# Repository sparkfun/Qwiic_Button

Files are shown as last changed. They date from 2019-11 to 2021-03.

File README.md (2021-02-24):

SparkFun Qwiic Button
========================================
<table class="table table-hover table-striped table-bordered">
  <tr align="center">
   <td></td>
   <td></td>
   <td></td>
  </tr>
  <tr align="center">
    <td><a href="https://www.sparkfun.com/products/15932">SparkFun Qwiic Button - Red <br />(BOB-15932)</a></td>
    <td><a href="https://www.sparkfun.com/products/16842">SparkFun Qwiic Button - Green <br />(BOB-16842)</a></td>
    <td><a href="https://www.sparkfun.com/products/15931">SparkFun Qwiic Button Breakout <br />(BOB-15931)</a></td>
  </tr>
</table>

The SparkFun Qwiic Button is an I<sup>2</sup>C enabled button with a built-in LED, interrupts, variable I<sup>2</sup>C address, and onboard button queues.

Repository Contents
-------------------

* **/Documentation** - Data sheets, additional product information
* **/Hardware** - Eagle design files (.brd, .sch)
* **/Firmware** - The latest firmware on the Qwiic Button boards
* **/Hardware/Production** - Production panel files (.brd)

Documentation
--------------
* **[SparkFun Qwiic Button Hookup Guide](https://learn.sparkfun.com/tutorials/sparkfun-qwiic-button-hookup-guide/all)** - Basic Hookup Guide.
* **[SparkFun Qwiic Button Arduino Library](https://github.com/sparkfun/SparkFun_Qwiic_Button_Arduino_Library)** - Arduino library for the Qwiic Button and Switch.
* **[SparkFun Qwiic Button Python Package](https://github.com/sparkfun/Qwiic_Button_Py)** - Python package for the Qwiic Button and Qwiic Switch

Product Versions
--------------

* [BOB-15932](https://www.sparkfun.com/products/15932) - SparkFun Red Version with red LED pushbutton
* [BOB-16842](https://www.sparkfun.com/products/16842) - SparkFun Red Version with green LED pushbutton
* [BOB-15931](https://www.sparkfun.com/products/15931) - SparkFun Red Version without button
* [SPX-15584](https://www.sparkfun.com/products/15584) - Original SparkX version of the Qwiic Button.

License Information
-------------------

This product is _**open source**_! 

Please review the LICENSE.md file for license information. 

If you have any questions or concerns on licensing, please contact technical support on our [SparkFun forums](https://forum.sparkfun.com/viewforum.php?f=152).

Distributed as-is; no warranty is given.

- Your friends at SparkFun.

_<COLLABORATION CREDIT>_

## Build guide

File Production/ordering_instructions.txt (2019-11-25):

panel size, 91x91mm
PCB thickness, 1.6mm
number of layers, 2
soldermask color, Black
silkscreen color, White
oz copper, 1oz
finish, HASL lead free
stencils, top+bottom
pcs per panel, 9
min trace width, 0.152400mm / 0.006000in
min drill size, 0.304800mm / 0.012000in

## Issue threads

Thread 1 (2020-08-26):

Pop queue not working as expected

alchitry, 2020-08-26:
### Subject of the issue
I'm trying to get the Qwiic button working with the RedBoard Turbo and have setup all the libraries and am able to talk to the button.

Stuff like button.isPressed() works exactly as expected. However, the queue stuff isn't quite working properly.

I thought I'd use the pressed queue to make sure I got an accurate count of how many times the button was pressed. I'm using button.isPressedQueueEmpty() to check if the queue is empty before calling button.popPressedQueue() to remove a press. However, popPressedQueue() doesn't seem to remove an element from the queue as expected.

After clicking the button once, isPressedQueueEmpty() returns false regardless of how many times popPressedQueue() is called. Also isPressedQueueFull() always returns true once I press the button 15 times.

I've checked the firmware of the button and it matches the latest in the GitHub (258, 0x01 major, 0x02 minor)

I've also tried writing 0x01 to pressedQueueStatus register directly and reading it back. It reads 0 so the popRequest bit is either never set or cleared when the request is supposedly processed.

### Your workbench
* What development board or microcontroller are you using?
RedBoard Turbo

* What version of hardware or breakout board are you using?
258 (current firmware)

* How is the breakout board wired to your microcontroller?
Qwiic

* How is everything being powered?
5V regulator to the RedBoard Turbo, button is powered over Qwiic

### Steps to reproduce
Connect button to RedBoard Turbo (or likely any Qwiic board).

Here's the code I used.

```
#include <SparkFun_Qwiic_Button.h>

const int BLUE_LED = 13;
const int RX_LED = PIN_LED_RXL; // RX LED on pin 25, we use the predefined PIN_LED_RXL to make sure
const int TX_LED = PIN_LED_TXL; // TX LED on pin 26, we use the predefined PIN_LED_TXL to make sure

QwiicButton hourUpButton;
QwiicButton hourDownButton;
QwiicButton minuteUpButton;
QwiicButton minuteDownButton;

void setup() {
  pinMode(BLUE_LED, OUTPUT);
  pinMode(RX_LED, OUTPUT);
  pinMode(TX_LED, OUTPUT);
  digitalWrite(RX_LED, LOW); // TX LED on

  SerialUSB.begin(9600);
  Wire.begin(); //Join I2C bus

  if (minuteDownButton.begin(0x67) == false)
    errorLoop();

  digitalWrite(RX_LED, HIGH); // TX LED off

  while (!SerialUSB);
  digitalWrite(BLUE_LED, HIGH); // Blue LED on
  SerialUSB.println("Starting");

}

void loop() {
  if (minuteDownButton.isPressedQueueEmpty() == false) {
    SerialUSB.println("Minute Down");
    minuteDownButton.popPressedQueue();
  }
  delay(100);
}

void errorLoop() {
  while (1) {
    digitalWrite(RX_LED, LOW); // RX LED on
    delay(333);
    digitalWrite(RX_LED, HIGH); // RX LED off
    digitalWrite(TX_LED, LOW); // TX LED on
    delay(333);
    digitalWrite(TX_LED, HIGH); // TX LED off
    digitalWrite(BLUE_LED, HIGH); // Blue LED on
    delay(333);
    digitalWrite(BLUE_LED, LOW); // Blue LED off
  }
}
```

### Expected behavior
Calling button.popPressedQueue() should remove a press from the queue.

The code should print "Minute Down" once per button press.

### Actual behavior
The queue isn't emptied.

The code prints "Minute Down" continuously after a single press.

wickedbeernut, 2021-02-26:
This bug was opened six months ago.  Can you please help me understand why it hasn't been fixed?  I just bought eight QWIIC buttons and switches and they're all unusable due to this bug.

It appears there are at least two issues ...

The way in which the queueStatusBitField is defined,
```
typedef union {
  struct {
    bool popRequest : 1; //This is bit 0. User mutable, user sets to 1 to pop from queue, we pop from queue and set the bit back to zero.
    bool isEmpty : 1; //user immutable, returns 1 or 0 depending on whether or not the queue is empty
    bool isFull : 1; //user immutable, returns 1 or 0 depending on whether or not the queue is full
    bool: 5;
  };
  uint8_t byteWrapped;
} queueStatusBitField;
```
is inconsistent with the way in which it's being initialized as part of the protectionMap (pressedQueueStatus and clickedQueueStatus),

```
memoryMap protectionMap = {
  0x00,       //id
  0x00,       //firmwareMinor
  0x00,       //firmwareMajor
  {1, 1, 1},  //buttonStatus {isPressed, hasBeenClicked, eventAvailable}
  {1, 1},     //interruptConfig {pressedEnable, clickedEnable}
  0xFFFF,     //buttonDebounceTime
  {0, 0, 1},  //pressedQueueStatus {isFull, isEmpty, popRequest}
  0x00000000, //pressedQueueFront
  0x00000000, //pressedQueueBack
  {0, 0, 1},  //clickedQueueStatus {isFull, isEmpty, popRequest}
  0x00000000, //clickedQueueFront
  0x00000000, //clickedQueueBack
  0xFF,       //ledBrightness
  0xFF,       //ledPulseGranularity
  0xFFFF,     //ledPulseCycleTime
  0xFFFF,     //ledPulseOffTime
  0xFF,       //i2cAddress
};
```

consequently, the popRequest bit is read-only rather than read/write.

The other issue is a byte-alignment issue with the memoryMap.  The uint16_t buttonDebounceTime falls on an odd byte boundary and is being padded.  All of the other fields are off by one byte.

```
typedef struct memoryMap {
  //Button Status/Configuration                       Register Address
  uint8_t id;                                             // 0x00 - Byte 0
  uint8_t firmwareMinor;                                  // 0x01 - Byte 1
  uint8_t firmwareMajor;                                  // 0x02 - Byte 2

  statusRegisterBitField buttonStatus;                    // 0x03 - Byte 3

  //Interrupt Configuration
  interruptConfigBitField interruptConfigure;            // 0x04  - Byte 4

  // <<< PADDED HERE - Byte 5

  uint16_t buttonDebounceTime;                            // 0x05  - Bytes 6 and 7

  //ButtonPressed queue manipulation and status functions
  queueStatusBitField pressedQueueStatus;                 // 0x07 - Byte 8
  unsigned long pressedQueueFront;                        // 0x08 - Bytes 9 through 12
  unsigned long pressedQueueBack;                         // 0x0C  - Bytes 13 through 16

  queueStatusBitField clickedQueueStatus;                 // 0x10 -  - Byte 17
  unsigned long clickedQueueFront;                        // 0x11  - Bytes 18 through 21
  unsigned long clickedQueueBack;                         // 0x15  - Bytes 22 through 25

  //LED Configuration
  uint8_t ledBrightness;                                  // 0x19 - Byte 26
  uint8_t ledPulseGranularity;                            // 0x1A - Byte 27
  uint16_t ledPulseCycleTime;                             // 0x1B - Bytes 28 and 29
  uint16_t ledPulseOffTime;                               // 0x1D - Bytes 30 and 31

  //Device Configuration
  uint8_t i2cAddress;                                     // 0x1F - Byte 32
};
```
I may be all wet.  My interpretation may be a function of the microcontroller I'm testing on.

Assuming I can fix the Qwiic_Button firmware, is there a way I can reprogram my QWIIC buttons and switches?  Or are they pretty much paperweights at this point?

englandsaurus, 2021-02-26:
@wickedbeernut  Are you using a SAMD microcontroller?

wickedbeernut, 2021-02-26:
> @wickedbeernut Are you using a SAMD microcontroller?

You got me there!  SparkFun SAMD51 Thing Plus.

I'll withdraw my comment with respect to the byte-alignment of the memoryMap.  However, I stand by my comment with respect to the way in which the queueStatusBitField is defined and initialized as part of the registerMap and protectionMap (pressedQueueStatus and clickedQueueStatus).

I compiled and uploaded the Qwiic_Button firmware to an Uno.  I added the following Serial.print statements to setup(),

```
  Serial.println();
  Serial.println("memoryMap");
  Serial.println("  Register: registerMap protectionMap");
  for (int x = 0; x < sizeof(memoryMap); x++) {
      Serial.print("    0x");
      Serial.print(x, HEX);
      Serial.print(": ");
      Serial.print(*(registerPointer + x), BIN);
      Serial.print(" ");
      Serial.println(*(protectionPointer + x), BIN);
  }

   bool popRequest;
   bool isEmpty;
   bool isFull;

   popRequest = protectionMap.pressedQueueStatus.popRequest;
   isEmpty = protectionMap.pressedQueueStatus.isEmpty;
   isFull = protectionMap.pressedQueueStatus.isFull;

   Serial.println();
   Serial.println("Protection Map");
   Serial.print("  pressedQueueStatus: ");
   Serial.println(*(protectionPointer + 7), BIN);
   Serial.print("    protectionMap.popRequest: ");
   Serial.println(popRequest);
   Serial.print("    protectionMap.isEmpty: ");
   Serial.println(isEmpty);
   Serial.print("    protectionMap.isFull: ");
   Serial.println(isFull);
   Serial.println();
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
Noam3kCH, 2021-03-02:
I'm also waiting for a solution here

makin-stuff, 2021-03-02:
@wickedbeernut @Noam3kCH I'm working on updating the firmware now. Will update and close this issue when I've got this bug fixed.

makin-stuff, 2021-03-08:
The firmware has been updated and will be present on future Qwiic Button batches. Thanks for your help @wickedbeernut. I've reached out to @Funda in tech support to see if he can issue you some new buttons. He should be reaching out shortly. Thanks

Funda, 2021-03-08:
@wickedbeernut Go ahead and fill out a return ticket here: https://www.sparkfun.com/returns - We will get you taken care of after the ticket has been submitted.

Cheers for now.

wickedbeernut, 2021-03-09:
> @wickedbeernut Go ahead and fill out a return ticket here: https://www.sparkfun.com/returns - We will get you taken care of after the ticket has been submitted.
>
> Cheers for now.

@Funda RMA submitted.  Thank you!

wickedbeernut, 2021-03-13:
> The firmware has been updated and will be present on future Qwiic Button batches. Thanks for your help @wickedbeernut. I've reached out to @Funda in tech support to see if he can issue you some new buttons. He should be reaching out shortly. Thanks

I'd ordered,

(5) Qwiic Switch (SPX-15586)
(2) SparkFun Qwiic Button Breakout (BOB-15931)
(1) Qwiic Arcade - Red (SPX-15591)

Support (@Funda?) is offering to refund my money for the two SparkFun Qwiic button breakout boards (BOB-15931).  Apparently, I'm stuck with the five Qwiic switches (SPX-15586) and arcade button (SPX-15591) because they're "SparkX" (whatever that means).  They all have the same embedded firmware bug.

I don't need a refund.  I need buttons and switches with the new firmware (v01.03).  I don't care if I have to pay for them yet again.  How do I go about ordering Qwiic buttons and switches with the new firmware?

Please help @makin-stuff!

wickedbeernut, 2021-03-18:
> The firmware has been updated and will be present on future Qwiic Button batches. Thanks for your help @wickedbeernut. I've reached out to @Funda in tech support to see if he can issue you some new buttons. He should be reaching out shortly. Thanks

@makin-stuff,

@Funda is refusing to issue me buttons with firmware version 1.3.  I recently purchased,

	(2) SparkFun Qwiic Button Breakout (BOB-15931)
	(5) Qwiic Switch (SPX-15586)
	(1) Qwiic Arcade - Red (SPX-15591)

Can you mail me buttons (BOB-15931) and/or switches (SPX-15586) with firmware version 1.3?  I can send you a Paypal payment?  $10 a piece plus shipping?

makin-stuff, 2021-03-18:
Hi there @wickedbeernut.
Thanks for all the work you did squashing the bug in the qwiic button firmware.
@Funda can send you 8 of [these Qwiic Buttons](https://www.sparkfun.com/products/15932) with the updated firmware.
As this is a minor firmware bug, we will be using the updated firmware on the **next batches built** of products [15931](https://www.sparkfun.com/products/15931) and [16842](https://www.sparkfun.com/products/16842). Unfortunately, we cannot guarantee any updated SPX products and additionally they cannot be refunded or returned. Please email @Funda if you wish to receive 8 of the Red LED Qwiic Buttons.
Please do not comment about this return on this Github issue anymore.

Closed 2021-03-08.

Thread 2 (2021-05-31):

Why do the queue status registers have bits for full and empty?

anahata0108, 2021-05-31:
I'm building a Rust driver for this button / LED and am using the register map as a reference to guide my implementation. The register map states that the Pressed Queue Status and Clicked Queue Status registers use bit 0 for whether the buffer is full and bit 1 for whether the buffer is empty. I'm not sure how to interpret this. Is it possible for both of these bits to be set? What  does that mean?

Closed 2021-05-31.

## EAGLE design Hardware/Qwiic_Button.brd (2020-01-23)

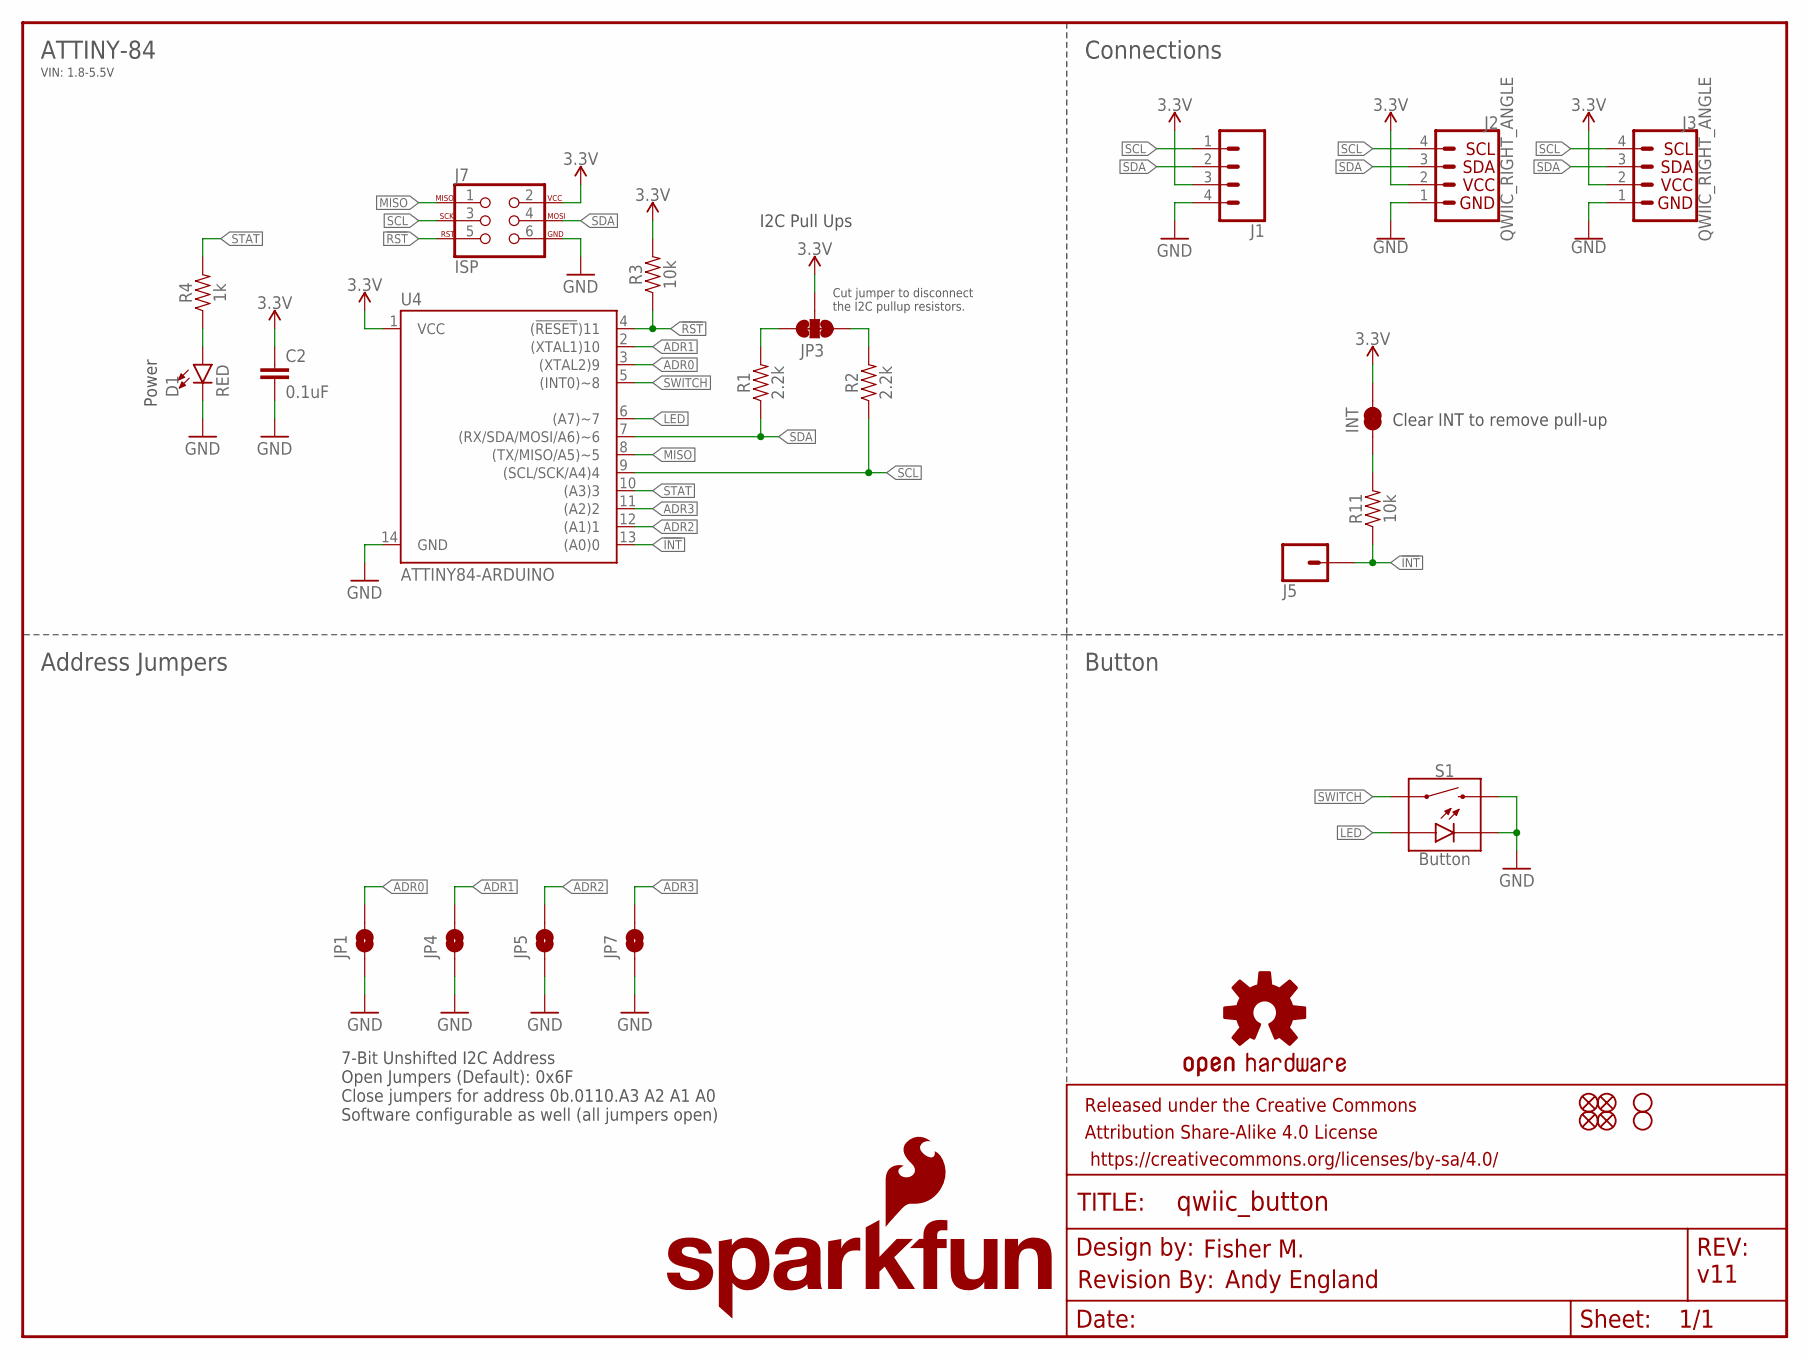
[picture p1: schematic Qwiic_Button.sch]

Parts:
C2: 0.1uF; 0603
D1: RED; LED-0603
FRAME1: FRAME-LETTER; CREATIVE_COMMONS
H1, H2: STAND-OFF
INT: JUMPER-SMT_2_NC_TRACE_SILK; SMT-JUMPER_2_NC_TRACE_SILK
J1: CONN_041X04_NO_SILK; 1X04_NO_SILK
J2, J3: QWIIC_RIGHT_ANGLE; JST04_1MM_RA
J5: CONN_01PTH_NO_SILK_YES_STOP; 1X01_NO_SILK
J7: ISP; 2X3_TEST_POINTS
JP1, JP4, JP5, JP7: JUMPER-SMT_2_NO_NO-SILK; SMT-JUMPER_2_NO_NO-SILK
JP2, JP6, JP8, JP9: FIDUCIALUFIDUCIAL; MICRO-FIDUCIAL
JP3: JUMPER-SMT_3_2-NC_TRACE_SILK; SMT-JUMPER_3_2-NC_TRACE_SILK
LOGO1: OSHW-LOGOMINI; OSHW-LOGO-MINI
LOGO2: REVISION
LOGO3: SFE_LOGO_NAME.1_INCH; SFE_LOGO_NAME_.1
LOGO4: SFE_LOGO_FLAME.1_INCH; SFE_LOGO_FLAME_.1
R1, R2: 2.2k; 0603
R3, R11: 10k; 0603
R4: 1k; 0603
S1: Button; TACTILE_SWITCH_LED_PTH_12MM
U4: ATTINY84-ARDUINO; SO14

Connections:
3.3V: C2.1, INT.2, J1.3, J2.2, J3.2, J7.2, JP3.2, R3.2, U4.1 (VCC)
!INT: J5.1, R11.1, U4.13 ((A0)0)
!RST: J7.5, R3.1, U4.4 ((!RESET!)11)
ADR0: JP1.2, U4.3 ((XTAL2)9)
ADR1: JP4.2, U4.2 ((XTAL1)10)
ADR2: JP5.2, U4.12 ((A1)1)
ADR3: JP7.2, U4.11 ((A2)2)
GND: C2.2, D1.C, J1.4, J2.1, J3.1, J7.6, JP1.1, JP4.1, JP5.1, JP7.1, S1.2, S1.C, U4.14 (GND)
INT_R: INT.1, R11.2
LED: S1.A, U4.6 ((A7)~7)
MISO: J7.1, U4.8 ((TX/MISO/A5)~5)
unnamed: D1.A, R4.1
SCL: J1.1, J2.4, J3.4, J7.3, R2.1, U4.9 ((SCL/SCK/A4)4)
SCL_PU1: JP3.1, R2.2
SDA: J1.2, J2.3, J3.3, J7.4, R1.1, U4.7 ((RX/SDA/MOSI/A6)~6)
SDA_PU1: JP3.3, R1.2
STAT: R4.2, U4.10 ((A3)3)
SWITCH: S1.4 (1), U4.5 ((INT0)~8)

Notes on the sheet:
v11
Connections
Cut jumper to disconnect the I2C pullup resistors.
7-Bit Unshifted I2C Address Open Jumpers (Default): 0x6F Close jumpers for address 0b.0110.A3 A2 A1 A0 Software configurable as well (all jumpers open)
I2C Pull Ups
Power
Clear INT to remove pull-up
Fisher M.
Andy England
ATTINY-84
Address Jumpers
Button
VIN: 1.8-5.5V

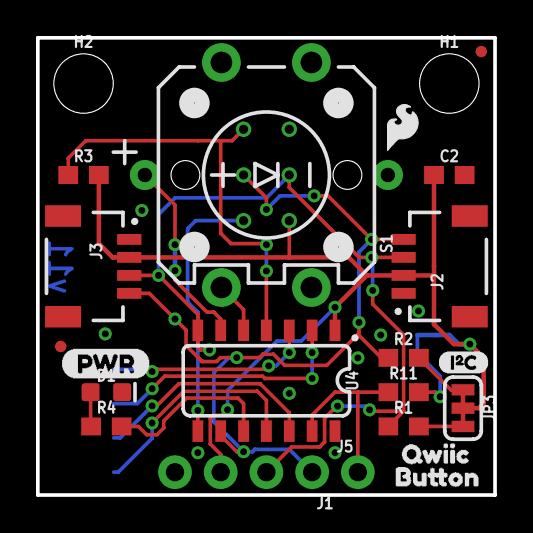
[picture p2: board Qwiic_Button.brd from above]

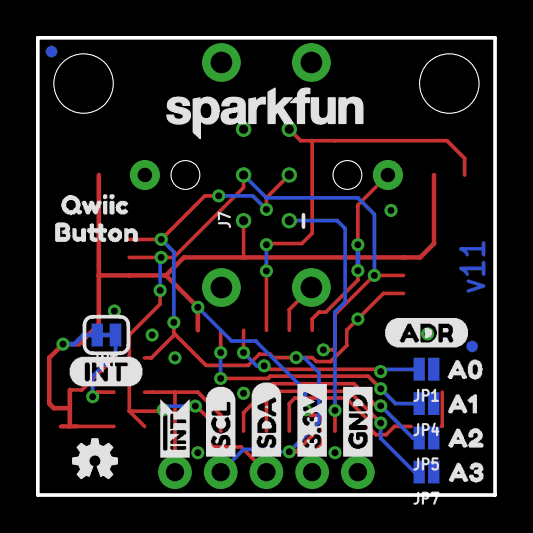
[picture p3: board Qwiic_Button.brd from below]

Board: 2 copper layers, 25.4 x 25.4 mm, 48 parts (23 on the bottom side), 18 nets.

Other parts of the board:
U$1, U$2: BUTTON1
U$3: PWR-()-04
U$4: INT-()-04
U$5: SCL
U$6: SDA
U$7: 3.3V
U$8: GND
U$9: (ADR)
U$10: I_SUPER2_C-()-03
U$15: INT#-[<-04
U$16: A00
U$17: A11
U$19: A22
U$20, U$23: QWIIC0
U$21: A33

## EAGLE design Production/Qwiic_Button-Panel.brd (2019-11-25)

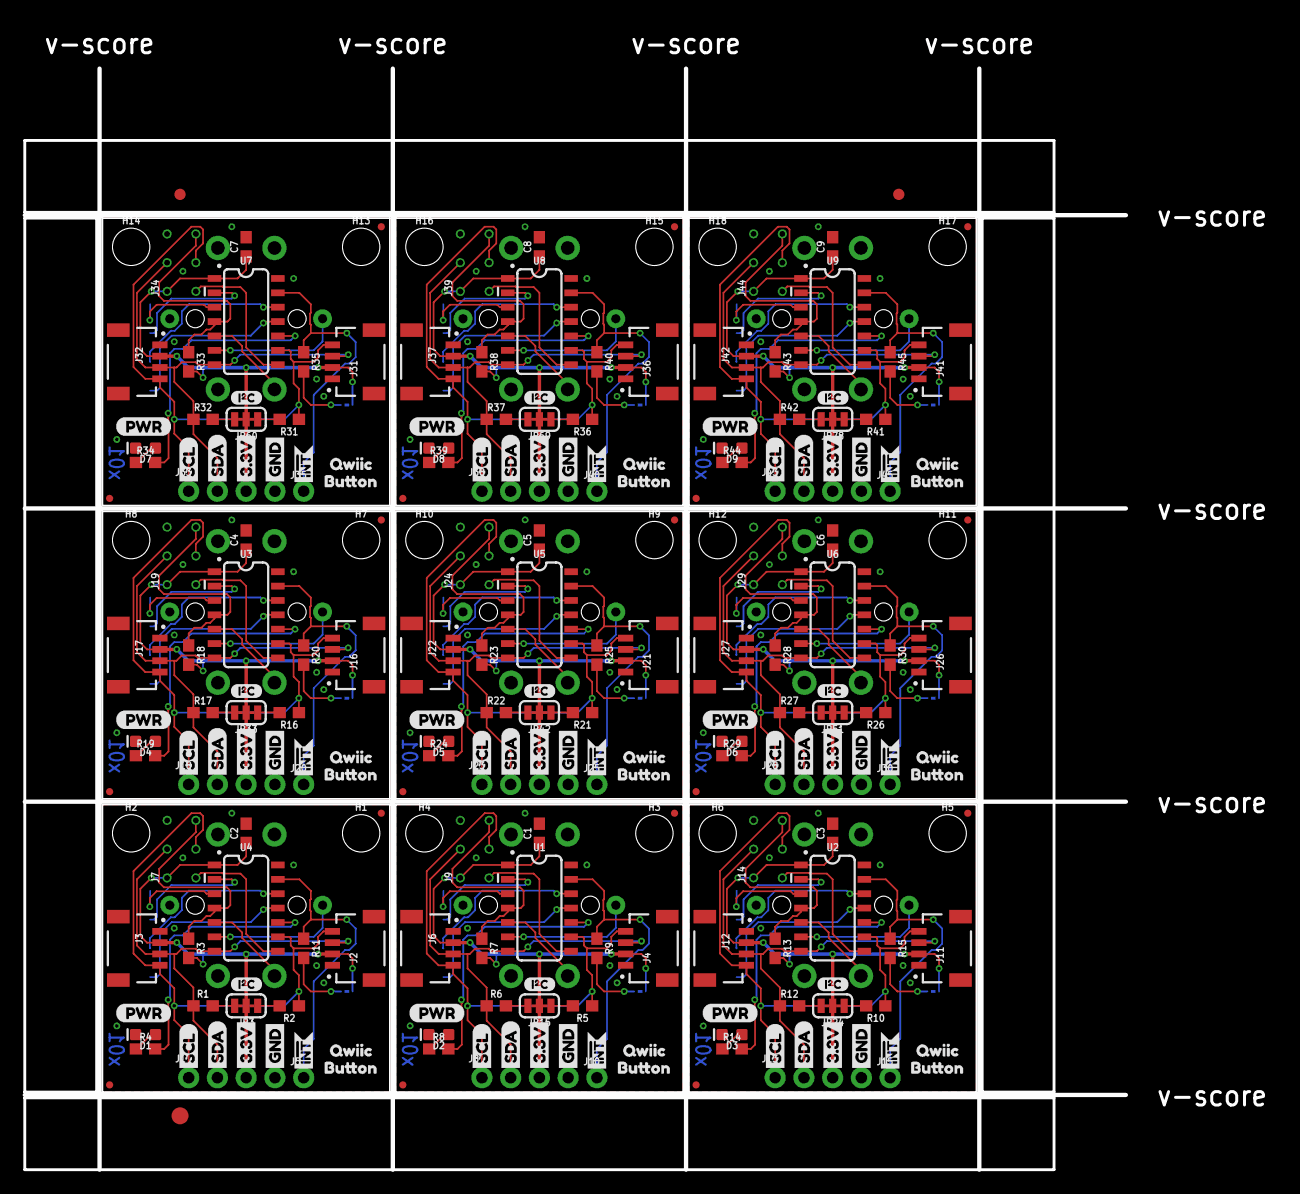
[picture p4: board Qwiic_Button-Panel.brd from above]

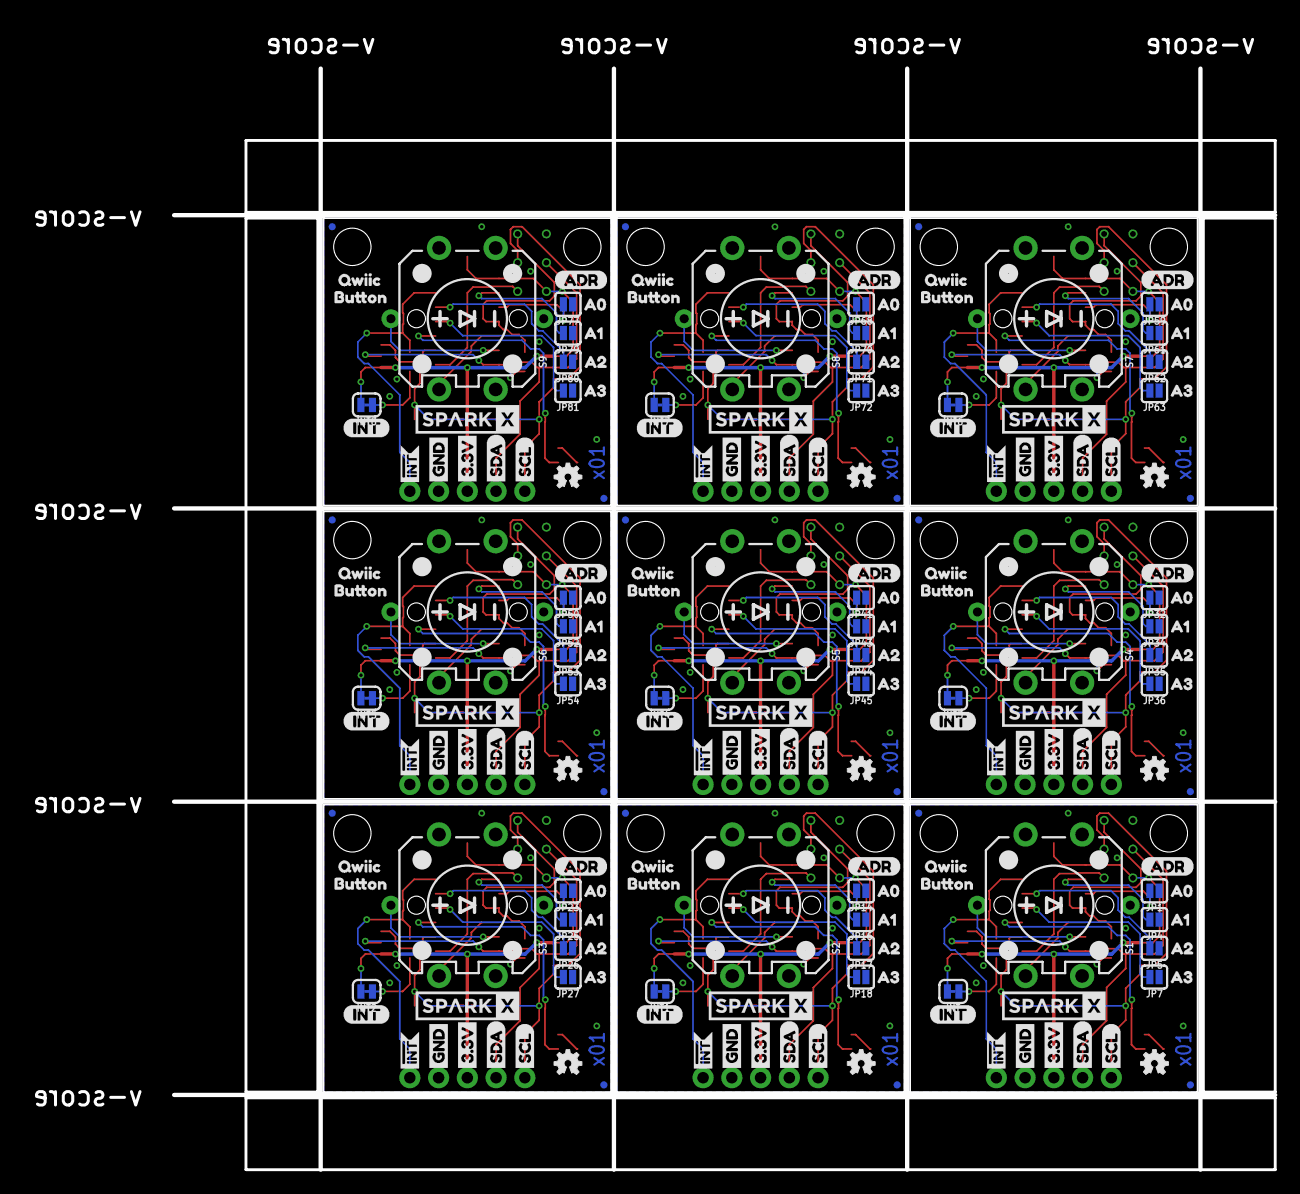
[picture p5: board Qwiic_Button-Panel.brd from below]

Board: 2 copper layers, 97.3 x 97.3 mm, 453 parts (207 on the bottom side), 162 nets.

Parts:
C1, C2, C3, C4, C5, C6, C7, C8, C9: 0.1uF; 0603
D1, D2, D3, D4, D5, D6, D7, D8, D9: RED; LED-0603
E$1, E$2: FIDUCIAL-1X2
E$3: FIDUCIAL-1.5X3
H1, H2, H3, H4, H5, H6, H7, H8, H9, H10, H11, H12, H13, H14, H15, H16, H17, H18: STAND-OFF
INT, INT1, INT2, INT3, INT4, INT5, INT6, INT7, INT8: SMT-JUMPER_2_NC_TRACE_SILK
J1, J8, J13, J18, J23, J28, J33, J38, J43: 1X04_NO_SILK
J2, J3, J4, J6, J11, J12, J16, J17, J21, J22, J26, J27, J31, J32, J36, J37, J41, J42: JST04_1MM_RA
J5, J10, J15, J20, J25, J30, J35, J40, J45: 1X01_NO_SILK
J7, J9, J14, J19, J24, J29, J34, J39, J44: ISP; 2X3_TEST_POINTS
JP1, JP4, JP5, JP7, JP14, JP16, JP17, JP18, JP23, JP25, JP26, JP27, JP32, JP34, JP35, JP36, JP41, JP43, JP44, JP45, JP50, JP52, JP53, JP54, JP59, JP61, JP62, JP63, JP68, JP70, JP71, JP72, JP77, JP79, JP80, JP81: SMT-JUMPER_2_NO_SILK
JP2, JP6, JP8, JP9, JP10, JP11, JP12, JP13, JP19, JP20, JP21, JP22, JP28, JP29, JP30, JP31, JP37, JP38, JP39, JP40, JP46, JP47, JP48, JP49, JP55, JP56, JP57, JP58, JP64, JP65, JP66, JP67, JP73, JP74, JP75, JP76: FIDUCIALUFIDUCIAL; MICRO-FIDUCIAL
JP3, JP15, JP24, JP33, JP42, JP51, JP60, JP69, JP78: SMT-JUMPER_3_2-NC_TRACE_SILK
LOGO1, LOGO2, LOGO3, LOGO4, LOGO5, LOGO6, LOGO7, LOGO8, LOGO9: OSHW-LOGOMINI; OSHW-LOGO-MINI
R1, R2, R5, R6, R10, R12, R16, R17, R21, R22, R26, R27, R31, R32, R36, R37, R41, R42: 2.2k; 0603
R3, R7, R9, R11, R13, R15, R18, R20, R23, R25, R28, R30, R33, R35, R38, R40, R43, R45: 10k; 0603
R4, R8, R14, R19, R24, R29, R34, R39, R44: 1k; 0603
S1, S2, S3, S4, S5, S6, S7, S8, S9: Button; TACTILE_SWITCH_LED_PTH_12MM
U1, U2, U3, U4, U5, U6, U7, U8, U9: ATTINY84-ARDUINO; SO14
U$1, U$2, U$38, U$39, U$61, U$62, U$84, U$85, U$107, U$108, U$130, U$131, U$153, U$154, U$176, U$177, U$199, U$200: BUTTON1
U$3, U$42, U$65, U$88, U$111, U$134, U$157, U$180, U$203: PWR-()-04
U$4, U$37, U$60, U$83, U$106, U$129, U$152, U$175, U$198: INT-()-04
U$5, U$14, U$24, U$34, U$47, U$57, U$70, U$80, U$93, U$103, U$116, U$126, U$139, U$149, U$162, U$172, U$185, U$195: SCL
U$6, U$12, U$25, U$33, U$48, U$56, U$71, U$79, U$94, U$102, U$117, U$125, U$140, U$148, U$163, U$171, U$186, U$194: SDA
U$7, U$22, U$26, U$30, U$49, U$53, U$72, U$76, U$95, U$99, U$118, U$122, U$141, U$145, U$164, U$168, U$187, U$191: 3.3V
U$8, U$13, U$27, U$29, U$50, U$52, U$73, U$75, U$96, U$98, U$119, U$121, U$142, U$144, U$165, U$167, U$188, U$190: GND
U$9, U$28, U$51, U$74, U$97, U$120, U$143, U$166, U$189: (ADR)
U$10, U$31, U$54, U$77, U$100, U$123, U$146, U$169, U$192: I_SUPER2_C-()-03
U$11, U$15, U$32, U$35, U$55, U$58, U$78, U$81, U$101, U$104, U$124, U$127, U$147, U$150, U$170, U$173, U$193, U$196: INT#-[<-04
U$16, U$43, U$66, U$89, U$112, U$135, U$158, U$181, U$204: A00
U$17, U$44, U$67, U$90, U$113, U$136, U$159, U$182, U$205: A11
U$18, U$36, U$59, U$82, U$105, U$128, U$151, U$174, U$197: SPARKX-MEDIUM
U$19, U$45, U$68, U$91, U$114, U$137, U$160, U$183, U$206: A22
U$20, U$23, U$40, U$41, U$63, U$64, U$86, U$87, U$109, U$110, U$132, U$133, U$155, U$156, U$178, U$179, U$201, U$202: QWIIC0
U$21, U$46, U$69, U$92, U$115, U$138, U$161, U$184, U$207: A33

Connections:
3.3V: C2.1, INT.2, J1.3, J2.2, J3.2, J7.2, JP3.2, R3.2, U4.1
3.3V1: C1.1, INT1.2, J4.2, J6.2, J8.3, J9.2, JP15.2, R7.2, U1.1
3.3V2: C3.1, INT2.2, J11.2, J12.2, J13.3, J14.2, JP24.2, R13.2, U2.1
3.3V3: C4.1, INT3.2, J16.2, J17.2, J18.3, J19.2, JP33.2, R18.2, U3.1
3.3V4: C5.1, INT4.2, J21.2, J22.2, J23.3, J24.2, JP42.2, R23.2, U5.1
3.3V5: C6.1, INT5.2, J26.2, J27.2, J28.3, J29.2, JP51.2, R28.2, U6.1
3.3V6: C7.1, INT6.2, J31.2, J32.2, J33.3, J34.2, JP60.2, R33.2, U7.1
3.3V7: C8.1, INT7.2, J36.2, J37.2, J38.3, J39.2, JP69.2, R38.2, U8.1
3.3V8: C9.1, INT8.2, J41.2, J42.2, J43.3, J44.2, JP78.2, R43.2, U9.1
!INT: J5.1, R11.1, U4.13
!INT1: J10.1, R9.1, U1.13
!INT2: J15.1, R15.1, U2.13
!INT3: J20.1, R20.1, U3.13
!INT4: J25.1, R25.1, U5.13
!INT5: J30.1, R30.1, U6.13
!INT6: J35.1, R35.1, U7.13
!INT7: J40.1, R40.1, U8.13
!INT8: J45.1, R45.1, U9.13
!RST: J7.5, R3.1, U4.4
!RST1: J9.5, R7.1, U1.4
!RST2: J14.5, R13.1, U2.4
!RST3: J19.5, R18.1, U3.4
!RST4: J24.5, R23.1, U5.4
!RST5: J29.5, R28.1, U6.4
!RST6: J34.5, R33.1, U7.4
!RST7: J39.5, R38.1, U8.4
!RST8: J44.5, R43.1, U9.4
ADR0: JP1.2, U4.3
ADR1: JP4.2, U4.2
ADR2: JP5.2, U4.12
ADR3: JP7.2, U4.11
ADR4: JP14.2, U1.3
ADR5: JP16.2, U1.2
ADR6: JP17.2, U1.12
ADR7: JP18.2, U1.11
ADR8: JP23.2, U2.3
ADR9: JP25.2, U2.2
ADR10: JP26.2, U2.12
ADR11: JP27.2, U2.11
ADR12: JP32.2, U3.3
ADR13: JP34.2, U3.2
ADR14: JP35.2, U3.12
ADR15: JP36.2, U3.11
ADR16: JP41.2, U5.3
ADR17: JP43.2, U5.2
ADR18: JP44.2, U5.12
ADR19: JP45.2, U5.11
ADR20: JP50.2, U6.3
ADR21: JP52.2, U6.2
ADR22: JP53.2, U6.12
ADR23: JP54.2, U6.11
ADR24: JP59.2, U7.3
ADR25: JP61.2, U7.2
ADR26: JP62.2, U7.12
ADR27: JP63.2, U7.11
ADR28: JP68.2, U8.3
ADR29: JP70.2, U8.2
ADR30: JP71.2, U8.12
ADR31: JP72.2, U8.11
ADR32: JP77.2, U9.3
ADR33: JP79.2, U9.2
ADR34: JP80.2, U9.12
ADR35: JP81.2, U9.11
GND: C2.2, D1.C, J1.4, J2.1, J3.1, J7.6, JP1.1, JP4.1, JP5.1, JP7.1, S1.2, S1.C, U4.14
GND1: C1.2, D2.C, J4.1, J6.1, J8.4, J9.6, JP14.1, JP16.1, JP17.1, JP18.1, S2.2, S2.C, U1.14
GND2: C3.2, D3.C, J11.1, J12.1, J13.4, J14.6, JP23.1, JP25.1, JP26.1, JP27.1, S3.2, S3.C, U2.14
GND3: C4.2, D4.C, J16.1, J17.1, J18.4, J19.6, JP32.1, JP34.1, JP35.1, JP36.1, S4.2, S4.C, U3.14
GND4: C5.2, D5.C, J21.1, J22.1, J23.4, J24.6, JP41.1, JP43.1, JP44.1, JP45.1, S5.2, S5.C, U5.14
GND5: C6.2, D6.C, J26.1, J27.1, J28.4, J29.6, JP50.1, JP52.1, JP53.1, JP54.1, S6.2, S6.C, U6.14
GND6: C7.2, D7.C, J31.1, J32.1, J33.4, J34.6, JP59.1, JP61.1, JP62.1, JP63.1, S7.2, S7.C, U7.14
GND7: C8.2, D8.C, J36.1, J37.1, J38.4, J39.6, JP68.1, JP70.1, JP71.1, JP72.1, S8.2, S8.C, U8.14
GND8: C9.2, D9.C, J41.1, J42.1, J43.4, J44.6, JP77.1, JP79.1, JP80.1, JP81.1, S9.2, S9.C, U9.14
INT_R: INT.1, R11.2
INT_R1: INT1.1, R9.2
INT_R2: INT2.1, R15.2
INT_R3: INT3.1, R20.2
INT_R4: INT4.1, R25.2
INT_R5: INT5.1, R30.2
INT_R6: INT6.1, R35.2
INT_R7: INT7.1, R40.2
INT_R8: INT8.1, R45.2
LED: S1.A, U4.6
LED1: S2.A, U1.6
LED2: S3.A, U2.6
LED3: S4.A, U3.6
LED4: S5.A, U5.6
LED5: S6.A, U6.6
LED6: S7.A, U7.6
LED7: S8.A, U8.6
LED8: S9.A, U9.6
MISO: J7.1, U4.8
MISO1: J9.1, U1.8
MISO2: J14.1, U2.8
MISO3: J19.1, U3.8
MISO4: J24.1, U5.8
MISO5: J29.1, U6.8
MISO6: J34.1, U7.8
MISO7: J39.1, U8.8
MISO8: J44.1, U9.8
unnamed: D2.A, R8.1
unnamed: D3.A, R14.1
unnamed: D1.A, R4.1
unnamed: D4.A, R19.1
unnamed: D5.A, R24.1
unnamed: D6.A, R29.1
unnamed: D7.A, R34.1
unnamed: D8.A, R39.1
unnamed: D9.A, R44.1
SCL: J1.1, J2.4, J3.4, J7.3, R2.1, U4.9
SCL1: J4.4, J6.4, J8.1, J9.3, R5.1, U1.9
SCL2: J11.4, J12.4, J13.1, J14.3, R10.1, U2.9
SCL3: J16.4, J17.4, J18.1, J19.3, R16.1, U3.9
SCL4: J21.4, J22.4, J23.1, J24.3, R21.1, U5.9
SCL5: J26.4, J27.4, J28.1, J29.3, R26.1, U6.9
SCL6: J31.4, J32.4, J33.1, J34.3, R31.1, U7.9
SCL7: J36.4, J37.4, J38.1, J39.3, R36.1, U8.9
SCL8: J41.4, J42.4, J43.1, J44.3, R41.1, U9.9
SCL_PU1: JP3.1, R2.2
SCL_PU2: JP15.1, R5.2
SCL_PU3: JP24.1, R10.2
SCL_PU4: JP33.1, R16.2
SCL_PU5: JP42.1, R21.2
SCL_PU6: JP51.1, R26.2
SCL_PU7: JP60.1, R31.2
SCL_PU8: JP69.1, R36.2
SCL_PU9: JP78.1, R41.2
SDA: J1.2, J2.3, J3.3, J7.4, R1.1, U4.7
SDA1: J4.3, J6.3, J8.2, J9.4, R6.1, U1.7
SDA2: J11.3, J12.3, J13.2, J14.4, R12.1, U2.7
SDA3: J16.3, J17.3, J18.2, J19.4, R17.1, U3.7
SDA4: J21.3, J22.3, J23.2, J24.4, R22.1, U5.7
SDA5: J26.3, J27.3, J28.2, J29.4, R27.1, U6.7
SDA6: J31.3, J32.3, J33.2, J34.4, R32.1, U7.7
SDA7: J36.3, J37.3, J38.2, J39.4, R37.1, U8.7
SDA8: J41.3, J42.3, J43.2, J44.4, R42.1, U9.7
SDA_PU1: JP3.3, R1.2
SDA_PU2: JP15.3, R6.2
SDA_PU3: JP24.3, R12.2
SDA_PU4: JP33.3, R17.2
SDA_PU5: JP42.3, R22.2
SDA_PU6: JP51.3, R27.2
SDA_PU7: JP60.3, R32.2
SDA_PU8: JP69.3, R37.2
SDA_PU9: JP78.3, R42.2
STAT: R4.2, U4.10
STAT1: R8.2, U1.10
STAT2: R14.2, U2.10
STAT3: R19.2, U3.10
STAT4: R24.2, U5.10
STAT5: R29.2, U6.10
STAT6: R34.2, U7.10
STAT7: R39.2, U8.10
STAT8: R44.2, U9.10
SWITCH: S1.4, U4.5
SWITCH1: S2.4, U1.5
SWITCH2: S3.4, U2.5
SWITCH3: S4.4, U3.5
SWITCH4: S5.4, U5.5
SWITCH5: S6.4, U6.5
SWITCH6: S7.4, U7.5
SWITCH7: S8.4, U8.5
SWITCH8: S9.4, U9.5

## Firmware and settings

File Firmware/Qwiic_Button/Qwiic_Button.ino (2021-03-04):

/*
  An I2C based Button
  By: Nathan Seidle and Fischer Moseley and Priyanka Makin
  SparkFun Electronics
  Date: July 31st, 2019
  License: This code is public domain but you buy me a beer if you use this and
  we meet someday (Beerware license).

  Qwiic Button is an I2C based button that records any button presses to a queue.

  Qwiic Button maintains a queue of events. To remove events from the queue write
  the appropriate register (timeSinceLastButtonClicked or timeSinceLastButtonPressed)
  to zero. The register will then be filled with the next available event time.

  There is also an accompanying Arduino Library located here:
  https://github.com/sparkfun/SparkFun_Qwiic_Button_Arduino_Library

  Feel like supporting our work? Buy a board from SparkFun!
  https://www.sparkfun.com/products/14641

  To install support for ATtiny84 in Arduino IDE: https://github.com/SpenceKonde/ATTinyCore/blob/master/Installation.md
  This core is installed from the Board Manager menu
  This core has built in support for I2C S/M and serial
  If you have Dave Mellis' ATtiny installed you may need to remove it from \Users\xx\AppData\Local\Arduino15\Packages

  To support 400kHz I2C communication reliably ATtiny84 needs to run at 8MHz. This requires user to
  click on 'Burn Bootloader' before code is loaded.

  Library Inclusion:
  Wire.h        Used for interfacing with the I2C hardware for responding to I2C events.
  EEPROM.h      Used for interfacing with the onboard EEPROM for storing and retrieving settings.
  nvm.h         Used for defining the storage locations in non-volatile memory (EEPROM) to store and retrieve settings from.
  queue.h       Used for defining a FIFO-queue that contains the timestamps associated with pressing and clicking the button.
  registers.h   Used for defining a memoryMap object that serves as the register map for the device.
  led.h         Used for configuring the behavior of the onboard LED (in the case of the Qwiic Button)
                  or the offboard LED (in the case of the Qwiic Switch)

  PinChangeInterrupt.h    Nico Hoo's library for triggering an interrupt on a pin state change (either low->high or high->low)
  avr/sleep.h             Needed for sleep_mode which saves power on the ATTiny
  avr/power.hardware      Needed for powering down peripherals such as the ADC/TWI and Timers on the ATTiny
*/

#include <Wire.h>
#include <EEPROM.h>
#include "nvm.h"
#include "queue.h"
#include "registers.h"
#include "led.h"

#include "PinChangeInterrupt.h" //Nico Hood's library: https://github.com/NicoHood/PinChangeInterrupt/
//Used for pin change interrupts on ATtinys (encoder button causes interrupt)
  /*** NOTE, PinChangeInterrupt library NEEDS a modification to work with this code.
  *** you MUST comment out this line: 
  *** https://github.com/NicoHood/PinChangeInterrupt/blob/master/src/PinChangeInterruptSettings.h#L228
  */

#include <avr/sleep.h> //Needed for sleep_mode
#include <avr/power.h> //Needed for powering down perihperals such as the ADC/TWI and Timers

#define DEVICE_ID 0x5D
#define FIRMWARE_MAJOR 0x01 //Firmware Version. Helpful for tech support.
#define FIRMWARE_MINOR 0x03

#define DEFAULT_I2C_ADDRESS 0x6F

#define SOFTWARE_ADDRESS true
#define HARDWARE_ADDRESS false

uint8_t oldAddress;

//Hardware connections
#if defined(__AVR_ATmega328P__)
//For developement on an Uno
const uint8_t addressPin0 = 3;
const uint8_t addressPin1 = 4;
const uint8_t addressPin2 = 5;
const uint8_t addressPin3 = 6;
const uint8_t ledPin = 9; //PWM
const uint8_t statusLedPin = 8;
const uint8_t switchPin = 2;
const uint8_t interruptPin = 7; //pin is active-low, high-impedance when not triggered, goes low-impedance to ground when triggered

#elif defined(__AVR_ATtiny84__)
const uint8_t addressPin0 = 9;
const uint8_t addressPin1 = 10;
const uint8_t addressPin2 = 1;
const uint8_t addressPin3 = 2;
const uint8_t ledPin = 7; //PWM
const uint8_t statusLedPin = 3;
const uint8_t switchPin = 8;
const uint8_t interruptPin = 0; //pin is active-low, high-impedance when not triggered, goes low-impedance to ground when triggered
#endif

//Global variables
//-=-=-=-=-=-=-=-=-=-=-=-=-=-=-=-=-=-=-=-=-=-=-=-=-=-=-=-=-=-=-=-=-=-=-=-=-=-=-=-=-=-=-=-=-=-
//These are the defaults for all settings

//Variables used in the I2C interrupt.ino file so we use volatile
volatile memoryMap registerMap {
  DEVICE_ID,           //id
  FIRMWARE_MINOR,      //firmwareMinor
  FIRMWARE_MAJOR,      //firmwareMajor
  {0, 0, 0},           //buttonStatus {eventAvailable, hasBeenClicked, isPressed}
  {1, 1},              //interruptConfig {clickedEnable, pressedEnable}
  0x000A,              //buttonDebounceTime
  {0, 1, 0},           //pressedQueueStatus {popRequest, isEmpty, isFull}
  0x00000000,          //pressedQueueFront
  0x00000000,          //pressedQueueBack
  {0, 1, 0},           //clickedQueueStatus {popRequest, isEmpty, isFull}
  0x00000000,          //clickedQueueFront
  0x00000000,          //clickedQueueBack
  0x00,                //ledBrightness
  0x01,                //ledPulseGranularity
  0x0000,              //ledPulseCycleTime
  0x0000,              //ledPulseOffTime
  DEFAULT_I2C_ADDRESS, //i2cAddress
};

//This defines which of the registers are read-only (0) vs read-write (1)
memoryMap protectionMap = {
  0x00,       //id
  0x00,       //firmwareMinor
  0x00,       //firmwareMajor
  {1, 1, 1},  //buttonStatus {eventAvailable, hasBeenClicked, isPressed}
  {1, 1},     //interruptConfig {clickedEnable, pressedEnable}
  0xFFFF,     //buttonDebounceTime
  {1, 0, 0},  //pressedQueueStatus {popRequest, isEmpty, isFull}
  0x00000000, //pressedQueueFront
  0x00000000, //pressedQueueBack
  {1, 0, 0},  //clickedQueueStatus {popRequest, isEmpty, isFull}
  0x00000000, //clickedQueueFront
  0x00000000, //clickedQueueBack
  0xFF,       //ledBrightness
  0xFF,       //ledPulseGranularity
  0xFFFF,     //ledPulseCycleTime
  0xFFFF,     //ledPulseOffTime
  0xFF,       //i2cAddress

};

//Cast 32bit address of the object registerMap with uint8_t so we can increment the pointer
uint8_t *registerPointer = (uint8_t *)&registerMap;
uint8_t *protectionPointer = (uint8_t *)&protectionMap;

volatile uint8_t registerNumber; //Gets set when user writes an address. We then serve the spot the user requested.

volatile boolean updateFlag = true; //Goes true when we receive new bytes from user. Causes LEDs and things to update in main loop.

volatile Queue ButtonPressed, ButtonClicked; //Init FIFO buffer for storing timestamps associated with button presses and clicks

volatile unsigned long lastClickTime = 0; //Used for debouncing

LEDconfig onboardLED; //init the onboard LED

//-=-=-=-=-=-=-=-=-=-=-=-=-=-=-=-=-=-=-=-=-=-=-=-=-=-=-=-=-=-=-=-=-=-=-=-=-=-=-=-=-=-=-=-=-=-

void setup(void)
{
  pinMode(addressPin0, INPUT_PULLUP); //Internally pull up address pins
  pinMode(addressPin1, INPUT_PULLUP);
  pinMode(addressPin2, INPUT_PULLUP);
  pinMode(addressPin3, INPUT_PULLUP);

  pinMode(ledPin, OUTPUT); //PWM
  analogWrite(ledPin, 0);

  pinMode(statusLedPin, OUTPUT); //No PWM
  digitalWrite(statusLedPin, 0);

  pinMode(switchPin, INPUT_PULLUP); //GPIO with internal pullup, goes low when button is pushed
#if defined(__AVR_ATmega328P__)
  pinMode(interruptPin, INPUT_PULLUP);     //High-impedance input until we have an int and then we output low. Pulled high with 10k with cuttable jumper.
#else
  pinMode(interruptPin, INPUT);     //High-impedance input until we have an int and then we output low. Pulled high with 10k with cuttable jumper.
#endif

  //Disable ADC
  ADCSRA = 0;

  //Disable Brown-Out Detect
  MCUCR = bit(BODS) | bit(BODSE);
  MCUCR = bit(BODS);

  //Power down various bits of hardware to lower power usage
  //set_sleep_mode(SLEEP_MODE_PWR_DOWN); //May turn off millis
  set_sleep_mode(SLEEP_MODE_IDLE);
  sleep_enable();

#if defined(__AVR_ATmega328P__)

  for (int x = 0; x < 100; x++) {
    EEPROM.put(x, 0xFF);
  }

  Serial.begin(115200);
  Serial.println("Qwiic Button");
  Serial.print("Address: 0x");
  Serial.println(registerMap.i2cAddress, HEX);
  Serial.print("Device ID: 0x");
  Serial.println(registerMap.id, HEX);

#endif

  readSystemSettings(&registerMap); //Load all system settings from EEPROM

#if defined(__AVR_ATmega328P__)
  //Debug values
  registerMap.ledBrightness = 255;     //Max brightness
  registerMap.ledPulseGranularity = 1; //Amount to change LED at each step

  registerMap.ledPulseCycleTime = 500; //Total amount of cycle, does not include off time. LED pulse disabled if zero.
  registerMap.ledPulseOffTime = 500;   //Off time between pulses
#endif

  onboardLED.update(&registerMap); //update LED variables, get ready for pulsing
  setupInterrupts();               //Enable pin change interrupts for I2C, switch, etc
  startI2C(&registerMap);          //Determine the I2C address we should be using and begin listening on I2C bus
  oldAddress = registerMap.i2cAddress;


  digitalWrite(statusLedPin, HIGH); //turn on the status LED to notify that we've setup everything properly
}

void loop(void)
{
  //Check to see if the I2C Address has been updated by software, set the appropriate address type flag
  if (oldAddress != registerMap.i2cAddress)
  {
    oldAddress = registerMap.i2cAddress;
    EEPROM.put(LOCATION_ADDRESS_TYPE, SOFTWARE_ADDRESS);
  }
  
  //update interruptPin output
  if ((registerMap.buttonStatus.isPressed && registerMap.interruptConfigure.pressedEnable) ||
      (registerMap.buttonStatus.hasBeenClicked && registerMap.interruptConfigure.clickedEnable))
  { //if the interrupt is triggered
    pinMode(interruptPin, OUTPUT); //make the interrupt pin a low-impedance connection to ground
    digitalWrite(interruptPin, LOW);
  }
  else
  { //go to high-impedance mode on the interrupt pin if the interrupt is not triggered
#if defined(__AVR_ATmega328P__)
    pinMode(interruptPin, INPUT_PULLUP);
#else
    pinMode(interruptPin, INPUT);
#endif
  }

  if (updateFlag == true)
  {




    //Record anything new to EEPROM (like new LED values)
    //It can take ~3.4ms to write a byte to EEPROM so we do that here instead of in an interrupt
    recordSystemSettings(&registerMap);

    //Calculate LED values based on pulse settings if anything has changed
    onboardLED.update(&registerMap);

    updateFlag = false; //clear flag
  }
  
  sleep_mode();             //Stop everything and go to sleep. Wake up if I2C event occurs.
  onboardLED.pulse(ledPin); //update the brightness of the LED
}

//Update slave I2C address to what's configured with registerMap.i2cAddress and/or the address jumpers.
void startI2C(memoryMap *map)
{
  uint8_t address;
  uint8_t addressType;
  EEPROM.get(LOCATION_ADDRESS_TYPE, addressType);

  if (addressType == 0xFF)
  {
    EEPROM.put(LOCATION_ADDRESS_TYPE, SOFTWARE_ADDRESS);
  }

  //Button PCB has 4 jumpers, the arcade/micro switch PCB has one. But we check all pins even when there
  //is no jumper (will always be high).
  uint8_t IOaddress = DEFAULT_I2C_ADDRESS;
  bitWrite(IOaddress, 0, digitalRead(addressPin0));
  bitWrite(IOaddress, 1, digitalRead(addressPin1));
  bitWrite(IOaddress, 2, digitalRead(addressPin2));
  bitWrite(IOaddress, 3, digitalRead(addressPin3));

  //If any of the address jumpers are set, we use jumpers
  if ((IOaddress != DEFAULT_I2C_ADDRESS) || (addressType == HARDWARE_ADDRESS))
  {
    address = IOaddress;
    EEPROM.put(LOCATION_ADDRESS_TYPE, HARDWARE_ADDRESS);
  }
  //If none of the address jumpers are set, we use registerMap (but check to make sure that the value is legal first)
  else
  {
    //if the value is legal, then set it
    if (map->i2cAddress > 0x07 && map->i2cAddress < 0x78)
      address = map->i2cAddress;

    //if the value is illegal, default to the default I2C address for our platform
    else
      address = DEFAULT_I2C_ADDRESS;
  }

  //save new address to the register map
  map->i2cAddress = address;

  //reconfigure Wire instance
  Wire.end();          //stop I2C on old address
  Wire.begin(address); //rejoin the I2C bus on new address

  //The connections to the interrupts are severed when a Wire.begin occurs, so here we reattach them
  Wire.onReceive(receiveEvent);
  Wire.onRequest(requestEvent);
}

//Reads the current system settings from EEPROM
//If anything looks weird, reset setting to default value
void readSystemSettings(memoryMap *map)
{
  //Read what I2C address we should use
  EEPROM.get(LOCATION_I2C_ADDRESS, map->i2cAddress);
  if (map->i2cAddress == 255)
  {
    map->i2cAddress = DEFAULT_I2C_ADDRESS; //By default, we listen for DEFAULT_I2C_ADDRESS
    EEPROM.put(LOCATION_I2C_ADDRESS, map->i2cAddress);
  }

  //Error check I2C address we read from EEPROM
  if (map->i2cAddress < 0x08 || map->i2cAddress > 0x77)
  {
    //User has set the address out of range
    //Go back to defaults
    map->i2cAddress = DEFAULT_I2C_ADDRESS;
    EEPROM.put(LOCATION_I2C_ADDRESS, map->i2cAddress);
  }

  //Read the interrupt bits
  EEPROM.get(LOCATION_INTERRUPTS, map->interruptConfigure.byteWrapped);
  if (map->interruptConfigure.byteWrapped == 0xFF)
  {
    map->interruptConfigure.byteWrapped = 0x03; //By default, enable the click and pressed interrupts
    EEPROM.put(LOCATION_INTERRUPTS, map->interruptConfigure.byteWrapped);
  }

  EEPROM.get(LOCATION_LED_PULSEGRANULARITY, map->ledPulseGranularity);
  if (map->ledPulseGranularity == 0xFF)
  {
    map->ledPulseGranularity = 0; //Default to none
    EEPROM.put(LOCATION_LED_PULSEGRANULARITY, map->ledPulseGranularity);
  }

  EEPROM.get(LOCATION_LED_PULSECYCLETIME, map->ledPulseCycleTime);
  if (map->ledPulseCycleTime == 0xFFFF)
  {
    map->ledPulseCycleTime = 0; //Default to none
    EEPROM.put(LOCATION_LED_PULSECYCLETIME, map->ledPulseCycleTime);
  }

  EEPROM.get(LOCATION_LED_PULSEOFFTIME, map->ledPulseOffTime);
  if (map->ledPulseOffTime == 0xFFFF)
  {
    map->ledPulseOffTime = 0; //Default to none
    EEPROM.put(LOCATION_LED_PULSECYCLETIME, map->ledPulseOffTime);
  }

  EEPROM.get(LOCATION_BUTTON_DEBOUNCE_TIME, map->buttonDebounceTime);
  if (map->buttonDebounceTime == 0xFFFF)
  {
    map->buttonDebounceTime = 10; //Default to 10ms
    EEPROM.put(LOCATION_BUTTON_DEBOUNCE_TIME, map->buttonDebounceTime);
  }

  //Read the starting value for the LED
  EEPROM.get(LOCATION_LED_BRIGHTNESS, map->ledBrightness);
  if (map->ledPulseCycleTime > 0)
  {
    //Don't turn on LED, we'll pulse it in main loop
    analogWrite(ledPin, 0);
  }
  else
  { //Pulsing disabled
    //Turn on LED to setting
    analogWrite(ledPin, map->ledBrightness);
  }
}

//If the current setting is different from that in EEPROM, update EEPROM
void recordSystemSettings(memoryMap *map)
{
  //I2C address is byte
  byte i2cAddr;

  //Error check the current I2C address
  if (map->i2cAddress >= 0x08 && map->i2cAddress <= 0x77)
  {
    //Address is valid

    //Read the value currently in EEPROM. If it's different from the memory map then record the memory map value to EEPROM.
    EEPROM.get(LOCATION_I2C_ADDRESS, i2cAddr);
    if (i2cAddr != map->i2cAddress)
    {
      EEPROM.put(LOCATION_I2C_ADDRESS, (byte)map->i2cAddress);
      startI2C(map); //Determine the I2C address we should be using and begin listening on I2C bus
    }
  }
  else
  {
    EEPROM.get(LOCATION_I2C_ADDRESS, i2cAddr);
    map->i2cAddress == i2cAddr; //Return to original address
  }


  EEPROM.put(LOCATION_INTERRUPTS, map->interruptConfigure.byteWrapped);
  EEPROM.put(LOCATION_LED_BRIGHTNESS, map->ledBrightness);
  EEPROM.put(LOCATION_LED_PULSEGRANULARITY, map->ledPulseGranularity);
  EEPROM.put(LOCATION_LED_PULSECYCLETIME, map->ledPulseCycleTime);
  EEPROM.put(LOCATION_LED_PULSEOFFTIME, map->ledPulseOffTime);
  EEPROM.put(LOCATION_BUTTON_DEBOUNCE_TIME, map->buttonDebounceTime);
}

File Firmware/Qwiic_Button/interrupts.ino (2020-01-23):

/******************************************************************************
  interrupts.ino
  Fischer Moseley @ SparkFun Electronics
  Original Creation Date: July 31, 2019

  This file contains the interrupt routines that are triggered upon an I2C write from
  master (receiveEvent), an I2C read (requestEvent), or a button state change
  (buttonInterrupt). These ISRs modify the registerMap state variable, and sometimes
  set a flag (updateFlag) that updates things in the main loop.

  This code is beerware; if you see me (or any other SparkFun employee) at the
  local, and you've found our code helpful, please buy us a round!

  Distributed as-is; no warranty is given.
******************************************************************************/

//Turn on interrupts for the various pins
void setupInterrupts() {
  //Attach interrupt to switch
  attachPCINT(digitalPinToPCINT(switchPin), buttonInterrupt, CHANGE);
}

//When Qwiic Button receives data bytes from Master, this function is called as an interrupt
void receiveEvent(int numberOfBytesReceived) {
  registerNumber = Wire.read(); //Get the memory map offset from the user

  //Begin recording the following incoming bytes to the temp memory map
  //starting at the registerNumber (the first byte received)
  for (uint8_t x = 0 ; x < numberOfBytesReceived - 1 ; x++) {
    uint8_t temp = Wire.read(); //We might record it, we might throw it away

    if ( (x + registerNumber) < sizeof(memoryMap)) {
      //Clense the incoming byte against the read only protected bits
      //Store the result into the register map
      *(registerPointer + registerNumber + x) &= ~*(protectionPointer + registerNumber + x); //Clear this register if needed
      *(registerPointer + registerNumber + x) |= temp & *(protectionPointer + registerNumber + x); //Or in the user's request (clensed against protection bits)
    }
  }

  //Update the ButtonPressed and ButtonClicked queues.
  //If the user has requested to pop the oldest event off the stack then do so!
  if (registerMap.pressedQueueStatus.popRequest) {
    //Update the register with the next-oldest timestamp
    ButtonPressed.pop();
    registerMap.pressedQueueBack = ButtonPressed.back();

    //Update the status register with the state of the ButtonPressed buffer
    registerMap.pressedQueueStatus.isFull = ButtonPressed.isFull();
    registerMap.pressedQueueStatus.isEmpty = ButtonPressed.isEmpty();

    //Clear the popRequest bit so we know the popping is done
    registerMap.pressedQueueStatus.popRequest = false;
  }

  //If the user has requested to pop the oldest event off the stack then do so!
  if (registerMap.clickedQueueStatus.popRequest) {
    //Update the register with the next-oldest timestamp
    ButtonClicked.pop();
    registerMap.clickedQueueBack = ButtonClicked.back();

    //Update the status register with the state of the ButtonClicked buffer
    registerMap.clickedQueueStatus.isFull = ButtonClicked.isFull();
    registerMap.clickedQueueStatus.isEmpty = ButtonClicked.isEmpty();

    //Clear the popRequest bit so we know the popping is done
    registerMap.clickedQueueStatus.popRequest = false;
  }

  updateFlag = true; //Update things like LED brightnesses in the main loop
}

//Respond to GET commands
//When Qwiic Button gets a request for data from the user, this function is called as an interrupt
//The interrupt will respond with bytes starting from the last byte the user sent to us
//While we are sending bytes we may have to do some calculations
void requestEvent() {
  registerMap.buttonStatus.isPressed = !digitalRead(switchPin); //have to take the inverse of the switch pin because the switch is pulled up, not pulled down

  //Calculate time stamps before we start sending bytes via I2C
  registerMap.pressedQueueBack = millis() - ButtonPressed.back();
  registerMap.pressedQueueFront = millis() - ButtonPressed.front();

  registerMap.clickedQueueBack = millis() - ButtonClicked.back();
  registerMap.clickedQueueFront = millis() - ButtonClicked.front();

  //This will write the entire contents of the register map struct starting from
  //the register the user requested, and when it reaches the end the master
  //will read 0xFFs.

  Wire.write((registerPointer + registerNumber), sizeof(memoryMap) - registerNumber);
}

//Called any time the pin changes state
void buttonInterrupt() {

  //Debounce
  if (millis() - lastClickTime < registerMap.buttonDebounceTime)
    return;
  lastClickTime = millis();

  registerMap.buttonStatus.eventAvailable = true;

  //Update the ButtonPressed queue and registerMap
  registerMap.buttonStatus.isPressed = !digitalRead(switchPin); //Take the inverse of the switch pin because the switch is pulled up
  ButtonPressed.push(millis() - registerMap.buttonDebounceTime);
  registerMap.pressedQueueStatus.isEmpty = ButtonPressed.isEmpty();
  registerMap.pressedQueueStatus.isFull = ButtonPressed.isFull();

  //Update the ButtonClicked queue and registerMap if necessary
  if (digitalRead(switchPin) == HIGH) { //User has released the button, we have completed a click cycle
    //update the ButtonClicked queue and then registerMap
    registerMap.buttonStatus.hasBeenClicked = true;
    ButtonClicked.push(millis() - registerMap.buttonDebounceTime);
    registerMap.clickedQueueStatus.isEmpty = ButtonClicked.isEmpty();
    registerMap.clickedQueueStatus.isFull = ButtonClicked.isFull();
  }

}

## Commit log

2019-12-02 post design review changes
    [Qwiic_Button.brd, Qwiic_Button.sch]
2019-12-03 post checklist changes
    [Qwiic_Button.sch]
2020-01-23 Update ReadMe
    Added links to SparkFun versions of Qwiic Button and Qwiic Button Breakout along with Hookup Guide. Updated photos for SparkFun version of Qwiic Buttons.
2020-01-23 cleaning repo for release, removing backup files
    [Qwiic_Button-Panel.GBL, Qwiic_Button-Panel.GBO, Qwiic_Button-Panel.GBS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]
2020-01-23 adding polarity marker to button
    [Qwiic_Button.brd, Qwiic_Button.sch]
2020-01-23 Update ReadMe
    Adding SparkX Product version for Qwiic Button (Red)
2021-03-04 Update to Firmware - v01.03
    Changes made:
    Bump firmware version number
    Add disclaimer on PicChangeInterrupt lib
    Fixed comments on the listed bits on memory map
    Fixed bit order of queue status bit lists in protection map
    Updated pop() function to set full bool to false AFTER the tail has been incremented
    [Qwiic_Button.ino]

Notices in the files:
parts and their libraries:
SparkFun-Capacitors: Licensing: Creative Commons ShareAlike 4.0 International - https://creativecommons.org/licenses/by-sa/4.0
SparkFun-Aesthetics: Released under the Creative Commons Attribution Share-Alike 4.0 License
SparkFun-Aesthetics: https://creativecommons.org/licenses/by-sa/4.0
